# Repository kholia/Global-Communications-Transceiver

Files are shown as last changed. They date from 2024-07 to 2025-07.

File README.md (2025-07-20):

# Intro

The `Global Communications Transceiver` project. Global-Communications-Transceiver
is a 5W radio transceiver which is rugged, simple, and reliable.

It is a `optionally silent` digital radio which can be heard almost all over
the world!

Note: Receiving amateur and CB radio traffic without any license is fine in
most countries - please check your local regulations to be sure. Transmitting
on amateur shortwave bands usually requires an amateur radio license but you
are free to transmit and experiment on the CB band.

https://en.wikipedia.org/wiki/Citizens_band_radio_in_India

## Render

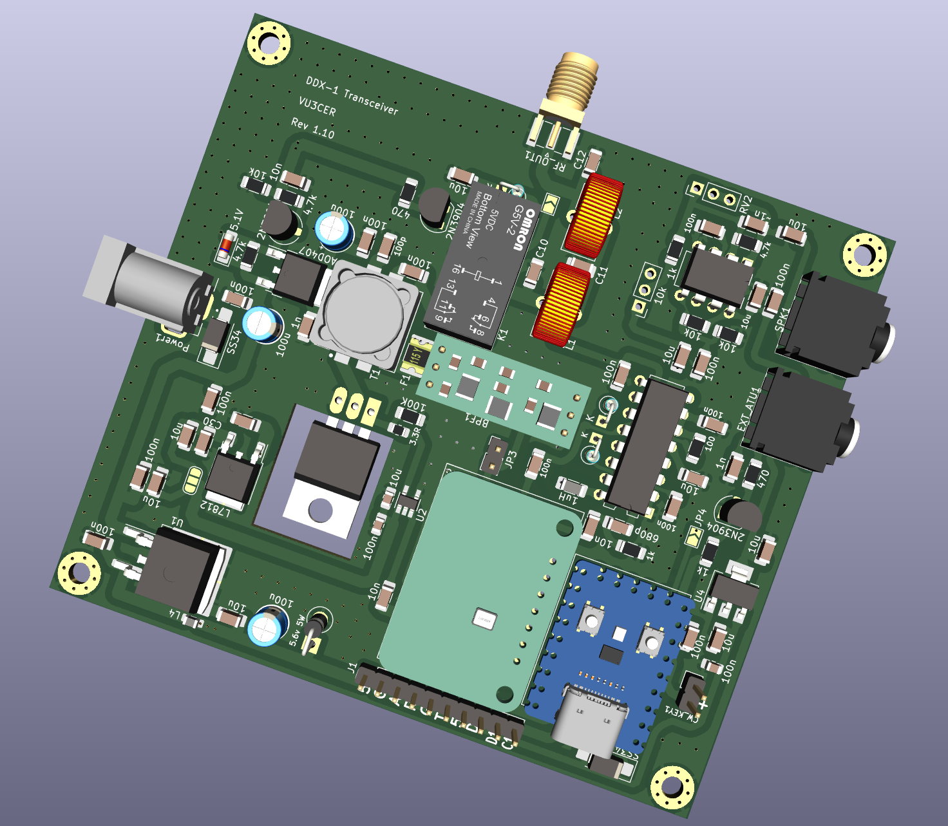
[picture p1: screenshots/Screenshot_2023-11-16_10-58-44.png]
Render


## Results

Sample contact from Pune to Medellin on 10m (15691km):

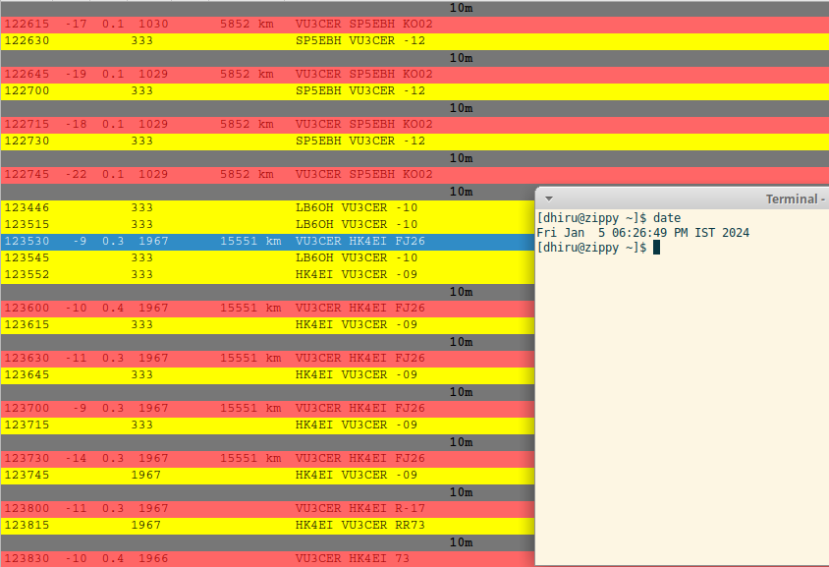
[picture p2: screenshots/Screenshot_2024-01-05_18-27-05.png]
Medellin QSO


Another sample conact with `WW1WW` (Pune to USA):

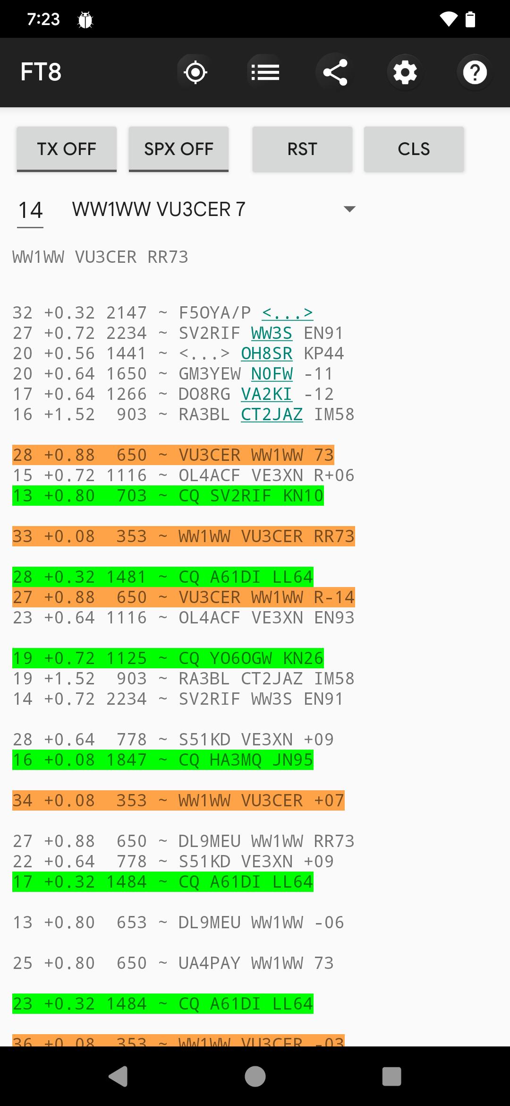
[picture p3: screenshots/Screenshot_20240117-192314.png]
USA QSO


## Features

- Single USB-C cable for handling both Audio + CAT control

- True 5W output on all HF bands. It even outputs ~1-2 W @ 50 MHz! (We now just
  need a 6m capable receiver section to build a 6m digital transceiver).

- Rock-solid PA which handles open, short, and bad SWR conditions (1:10 SWR
  tested). We knowingly stress-test it with untuned antennas and still manage
  DX (not a recommended practice for sure though).

- Rock-steady VFO which does NOT drift even under exposed conditions.  Yes - it
  receives WSPR at 28 MHz just fine.

- Reliable T/R switching based on a DPDT relay

- Switchable BPF support to get rid of BCI and other interferences (tested
  against OTH radar + 100 kW AM station in close visual proximity)

- No toroids to wind assuming an external LPF bank is in use ;-)

- The IRF510 final remains as cool as a cucumber (Class-D operation).

- Avoids problems associated with the 'audio frequency counting' approach used
  by earlier designs. Our transceiver has a bit-perfect, deterministic TX output.

- Supports largely automated assembly from JLCPCB (all the required files are
  in the same GitHub repository)

- It comes with a free, open-source AGPLv3 licensed firmware.

- No calibration is (ever) required. Just pick it up and it is ready to go
  on air.

- Low cost (20 to 30 USD is our BOM estimate)

- Stress tested by WSJT-Z for multiple days

- It routinely receives FT8 traffic from 80 to 100+ countries using a simple 5m
  long EFHW antenna

## RX Performance

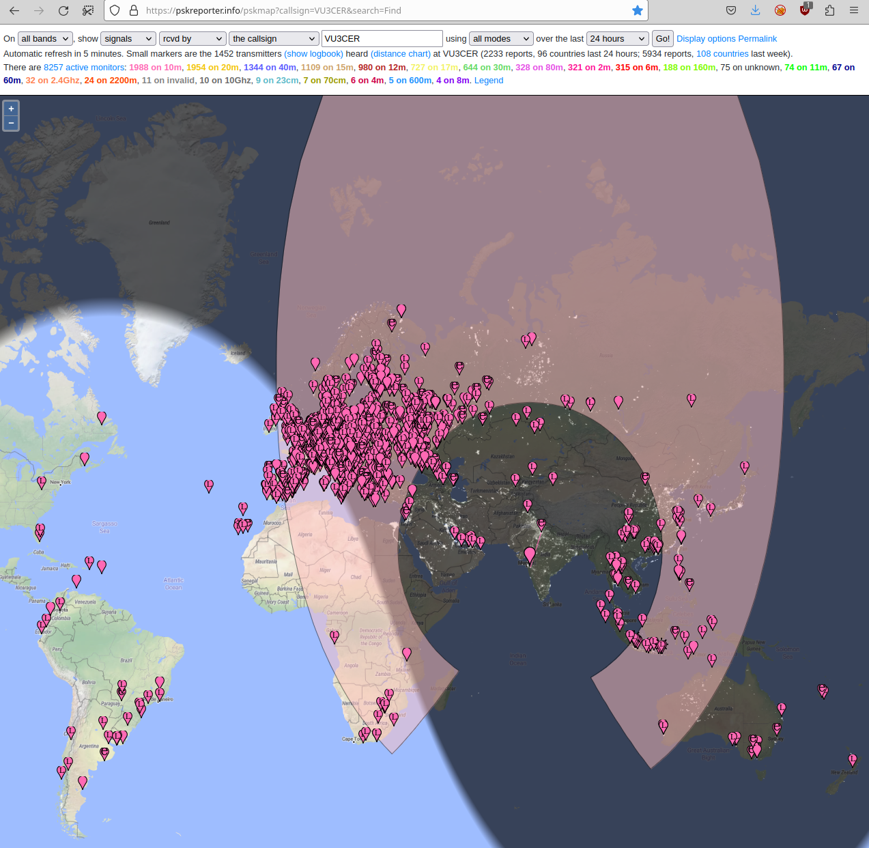
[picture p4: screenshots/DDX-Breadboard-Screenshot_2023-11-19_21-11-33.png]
RX Performance


Performance of CD2003-with-BPF is >= 80% of that of RSP1 SDR, at least!

## TX Performance

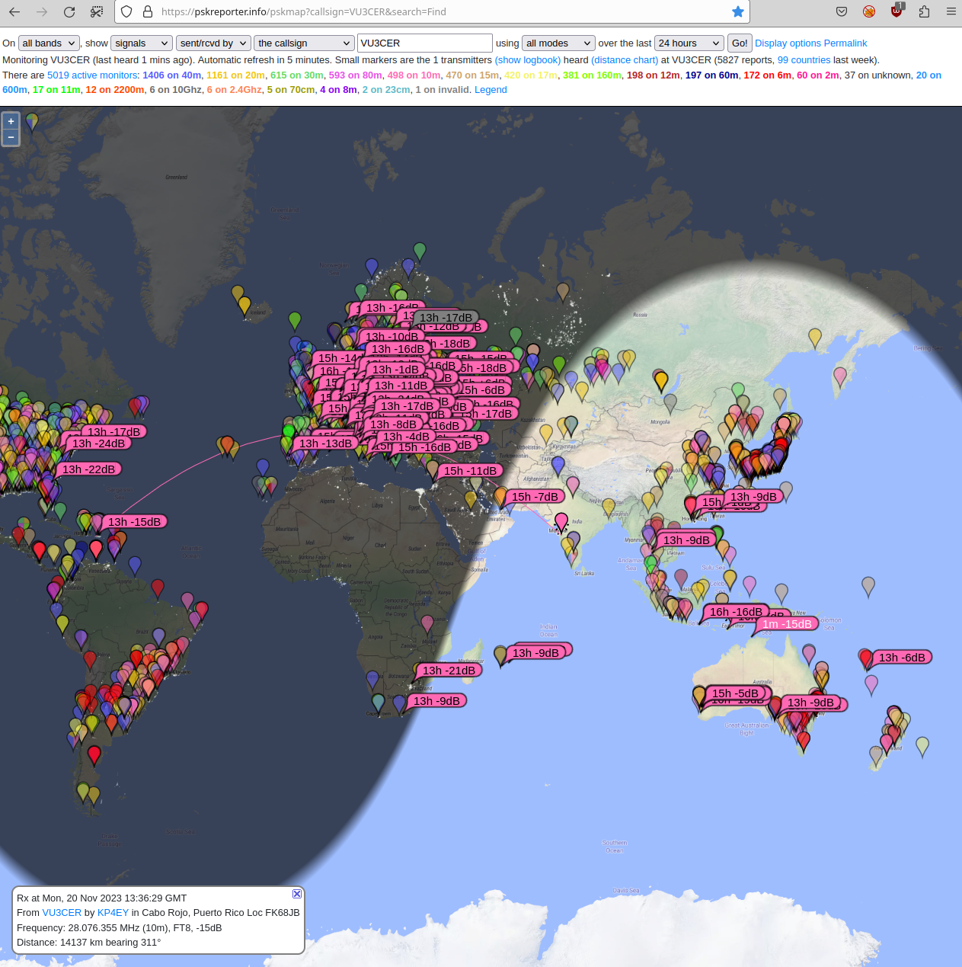
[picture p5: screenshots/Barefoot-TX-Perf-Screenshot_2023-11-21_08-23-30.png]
TX Performance


## VFO stability

It receives WSPR @ 28 MHz ;)

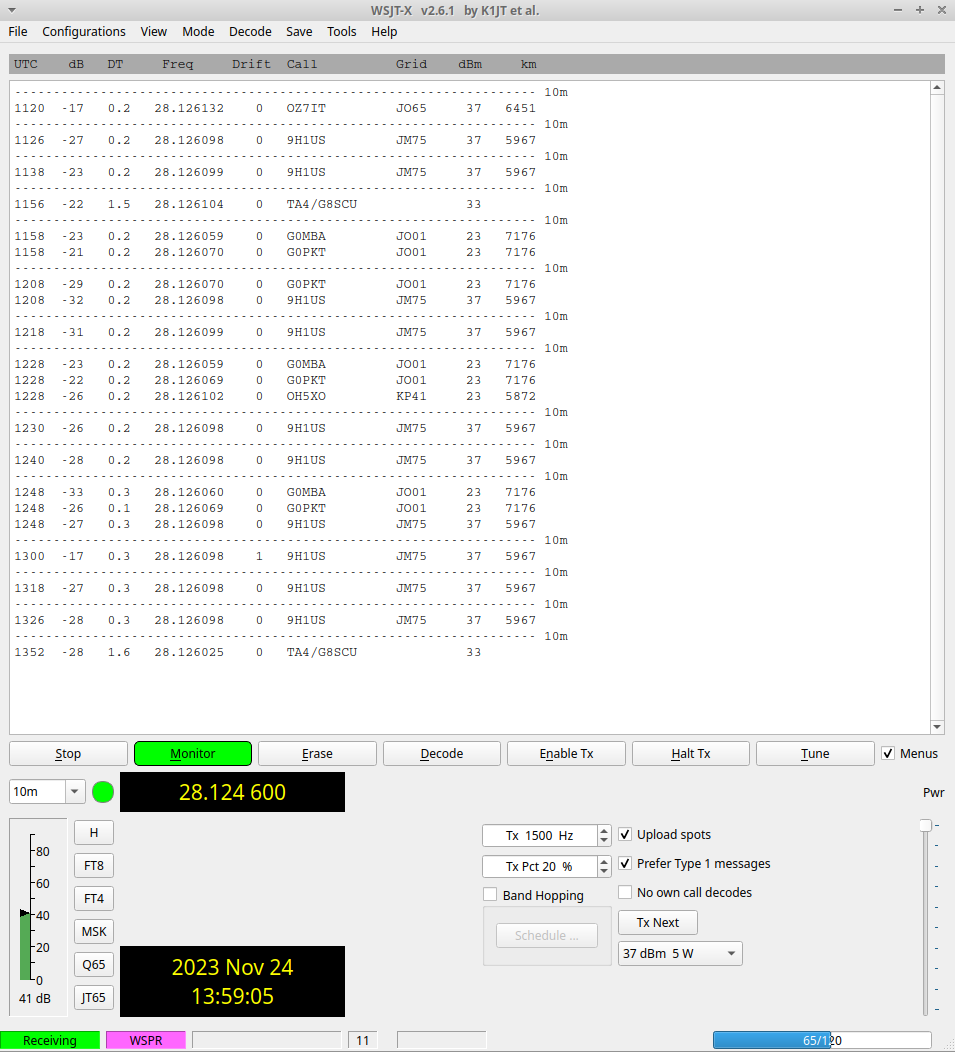
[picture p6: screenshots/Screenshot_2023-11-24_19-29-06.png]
WSPR stability


## WSPR TX Performance

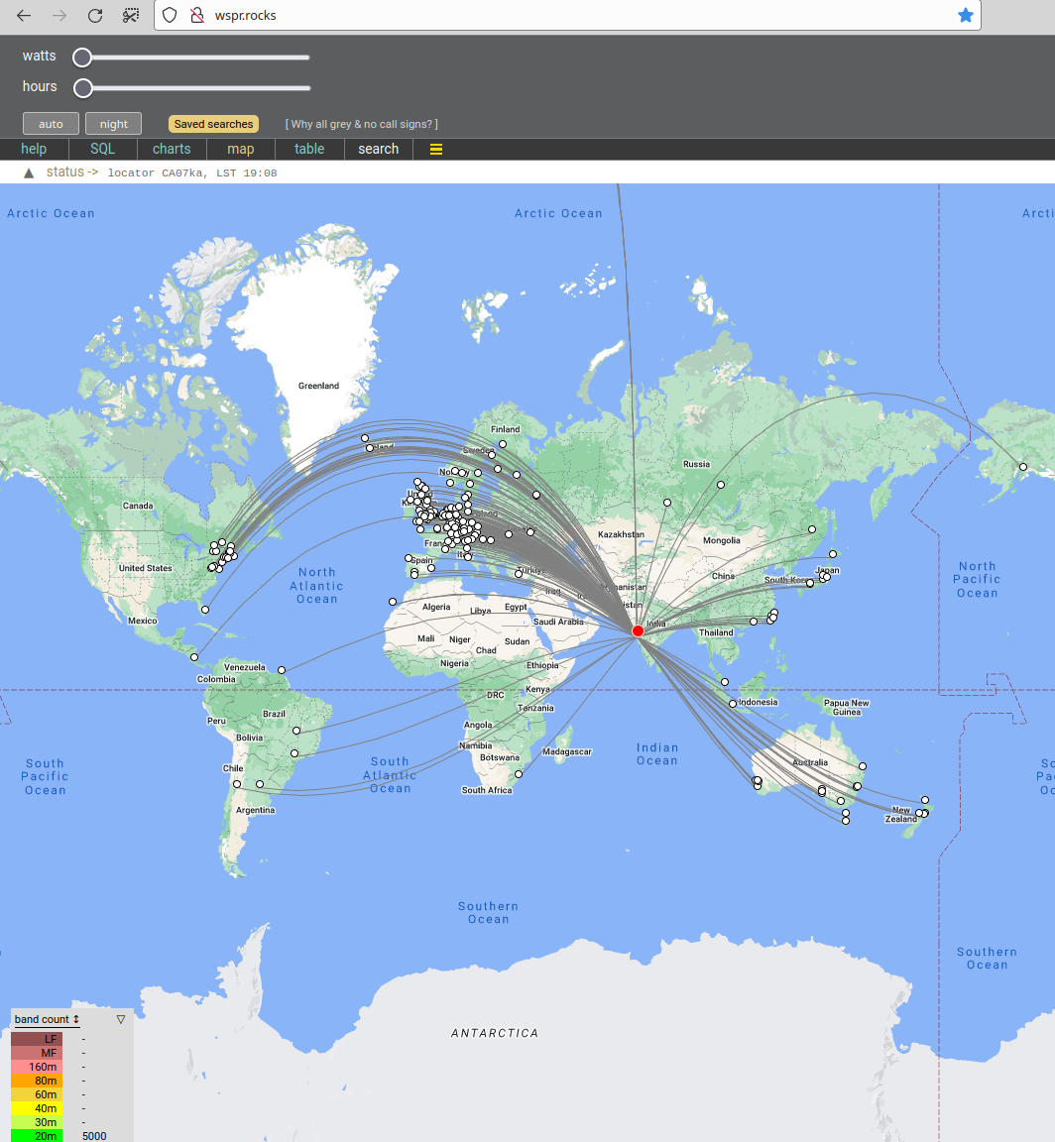
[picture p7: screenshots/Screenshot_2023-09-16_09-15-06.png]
WSPR TX performance


## Files

With these files, you can get around 80% pre-assembled boards (with the SMD
components soldered) from JLCPCB at a minimal cost.

- [BOM](./design-files/HF-PA-v10.csv)

- [Gerbers + PCBA files](./design-files/jlcpcb/production_files)

- [Schematic](./design-files/Schematics.pdf)

Note: The Si5351+TCXO boards can be ordered in fully assembled form from
JLCPCB. https://github.com/kholia/Si5351-Module-Clone-TCXO/ has the required
files (use the `-v4` folder).

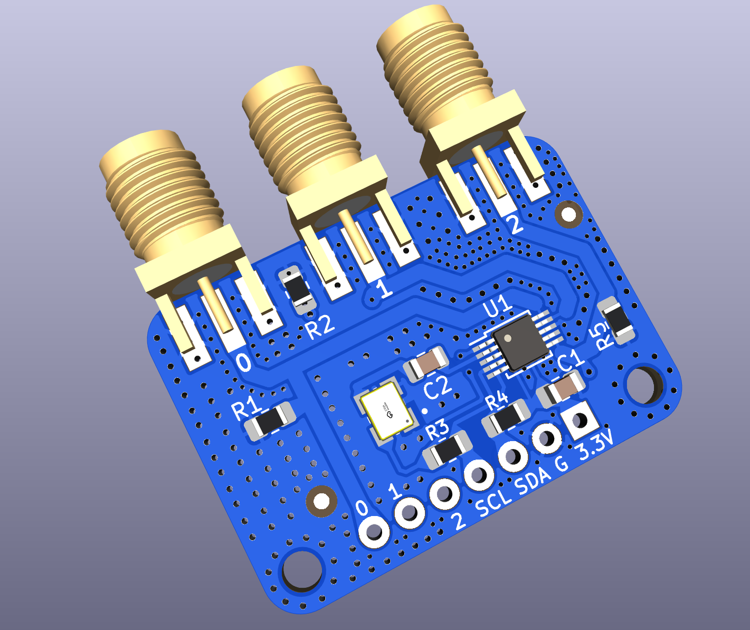
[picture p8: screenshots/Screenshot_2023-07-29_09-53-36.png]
Si5351 TCXO boards


JLCPCB link: https://jlcpcb.com/

JLCPCB ordering guide: https://github.com/WB2CBA/ADX-UnO-V1.3/ has the JLCPCB
ordering guide in it.

## Building the firmware (for Linux users)

Shortcut: Upload the pre-built `.uf2` file to the RP2040 Board and skip
to the next section.

Install dependencies:

```
sudo apt install cmake gcc-arm-none-eabi libnewlib-arm-none-eabi \
  libstdc++-arm-none-eabi-newlib git libusb-1.0-0-dev build-essential \
  make g++ gcc
```

```
mkdir ~/repos
cd ~/repos
```

```
git clone --recursive https://github.com/kholia/tinyusb.git  # use this in pico-sdk
git clone --recursive https://github.com/raspberrypi/pico-sdk.git
git clone --recursive https://github.com/kholia/Global-Communications-Transceiver.git
```

Now build the firmware using instructions in the `firmware` folder.

Load the built `.uf2` file into the MCU board. Process: Hold the BOOT button on
RP2040-Zero, and then connect it to a computer. Release the BOOT button. A new
drive will open on the computer. Just drag the .uf2 firmware file (included in
the repository) to this new drive. Done!

## Power sources

The transceiver was tested with the following power sources.

- SUGON 3005D Adjustable Digital DC Power - RECOMMENDED

- 3S "12V" Li-ion 18650 battery pack (RECOMMENDED for field operations)

- RUIDENG DPS5020 power supply module (@13v) powered by MEAN WELL / Mornsun SMPS

## Tips and Hints

- Do NOT use the internal LPF + BPF filters. Just use https://github.com/kholia/DDX/tree/master/RX-TX-BPF-2025-v2 externally.

- IRF510 needs to be insulated from the heat sink.

- You can ignore the `External ATU jack` stuff.

- Use a Common-Mode-Choke (attached between the rig, and the antenna) for
  safety against `return/back RF`.

- DDX works seamlessly with https://play.google.com/store/apps/details?id=com.bunzee.ft8radio app!

## Resources

- The `Global Communications Transceiver` project comes from our DDX family of
  transceiver designs - https://github.com/kholia/DDX/

- https://rf-tools.com/lc-filter/

- https://github.com/WB2CBA/ADX (the design that started it all)

- http://www.learningaboutelectronics.com/Articles/Low-pass-filter-calculator.php

- https://github.com/kholia/ConsensusBasedTimeSync (receiver comes from here)

- https://github.com/kholia/Si5351-Module-Clone-TCXO/ (VFO comes from here)

- https://github.com/kholia/HF-PA-v10 (PA comes from here)

  Ruggedness philosophy: https://www.youtube.com/watch?v=4r7wHMg5Yjg

- https://www.kk5jy.net/three-wire-gp/ (recommended antenna - superb for DX)

- https://github.com/kholia/HF-Balcony-Antenna-System (another portable antenna setup)

- https://github.com/batica81/microphone-library-for-pico (Vojislav's work makes DDX-1 possible)

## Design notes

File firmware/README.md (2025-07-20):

Build Process:

NB: https://github.com/hathach/tinyusb/pull/3181

```
export PICO_SDK_PATH=$HOME/repos/pico-sdk

export PICO_BOARD=waveshare_rp2040_zero  # note

cmake .

cmake -DCMAKE_BUILD_TYPE=Release .

make -j8
```

```
$ pacmd list-sources
...
  * index: 4
	name: <alsa_input.usb-PaniRCorp_MicNode_123456-00.mono-fallback>
	driver: <module-alsa-card.c>
	flags: HARDWARE HW_MUTE_CTRL HW_VOLUME_CTRL DECIBEL_VOLUME LATENCY DYNAMIC_LATENCY
	state: RUNNING
	suspend cause: (none)
	priority: 9040
	volume: mono: 65536 / 100% / 0.00 dB
	        balance 0.00
	base volume: 64662 /  99% / -0.35 dB
	volume steps: 65537
	muted: no
	current latency: 2.54 ms
	max rewind: 0 KiB
	sample spec: s16le 1ch 16000Hz
	channel map: mono
	             Mono
	used by: 1
	linked by: 1
	configured latency: 24.99 ms; range is 0.50 .. 2000.00 ms
	card: 7 <alsa_card.usb-PaniRCorp_MicNode_123456-00>
	module: 31
	properties:
		alsa.resolution_bits = "16"
		device.api = "alsa"
		device.class = "sound"
		alsa.class = "generic"
		alsa.subclass = "generic-mix"
		alsa.name = "USB Audio"
		alsa.id = "USB Audio"
		alsa.subdevice = "0"
		alsa.subdevice_name = "subdevice #0"
		alsa.device = "0"
		alsa.card = "4"
		alsa.card_name = "MicNode"
		alsa.long_card_name = "PaniRCorp MicNode at usb-0000:04:00.4-1.3.2, full speed"
		alsa.driver_name = "snd_usb_audio"
		device.bus_path = "pci-0000:04:00.4-usb-0:1.3.2:1.0"
		sysfs.path = "/devices/pci0000:00/0000:00:08.1/0000:04:00.4/usb3/3-1/3-1.3/3-1.3.2/3-1.3.2:1.0/sound/card4"
		udev.id = "usb-PaniRCorp_MicNode_123456-00"
		device.bus = "usb"
		device.vendor.id = "cafe"
		device.vendor.name = "PaniRCorp"
		device.product.id = "4011"
		device.product.name = "MicNode"
		device.serial = "PaniRCorp_MicNode_123456"
		device.string = "hw:4"
		device.buffering.buffer_size = "64000"
		device.buffering.fragment_size = "32000"
		device.access_mode = "mmap+timer"
		device.profile.name = "mono-fallback"
		device.profile.description = "Mono"
		device.description = "MicNode Mono"
		module-udev-detect.discovered = "1"
		device.icon_name = "audio-card-usb"
	ports:
		analog-input-mic: Microphone (priority 8700, latency offset 0 usec, available: yes)
			properties:
				device.icon_name = "audio-input-microphone"
	active port: <analog-input-mic>
```

The latency and peformance of the emulated microphone is fine. Check by
recording from this device using Audacity.

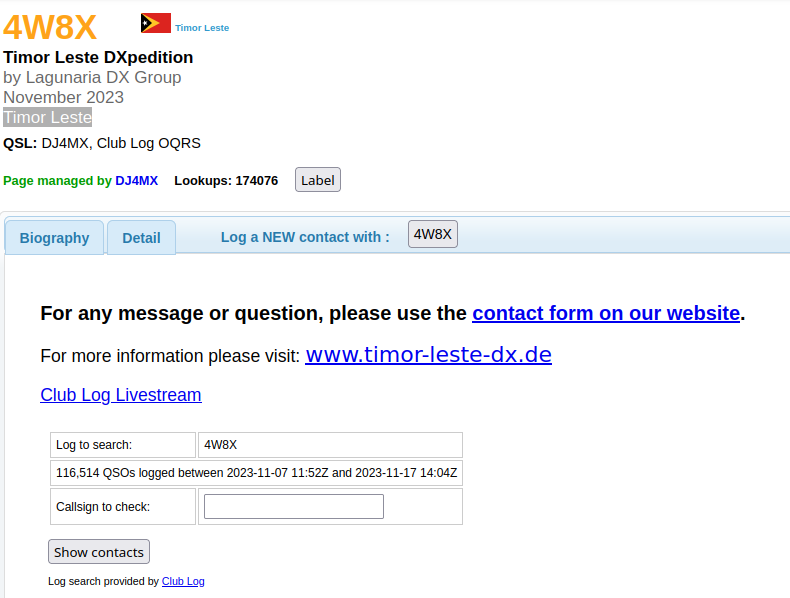
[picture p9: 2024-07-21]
screenshots/Screenshot_2023-11-17_19-35-13.png

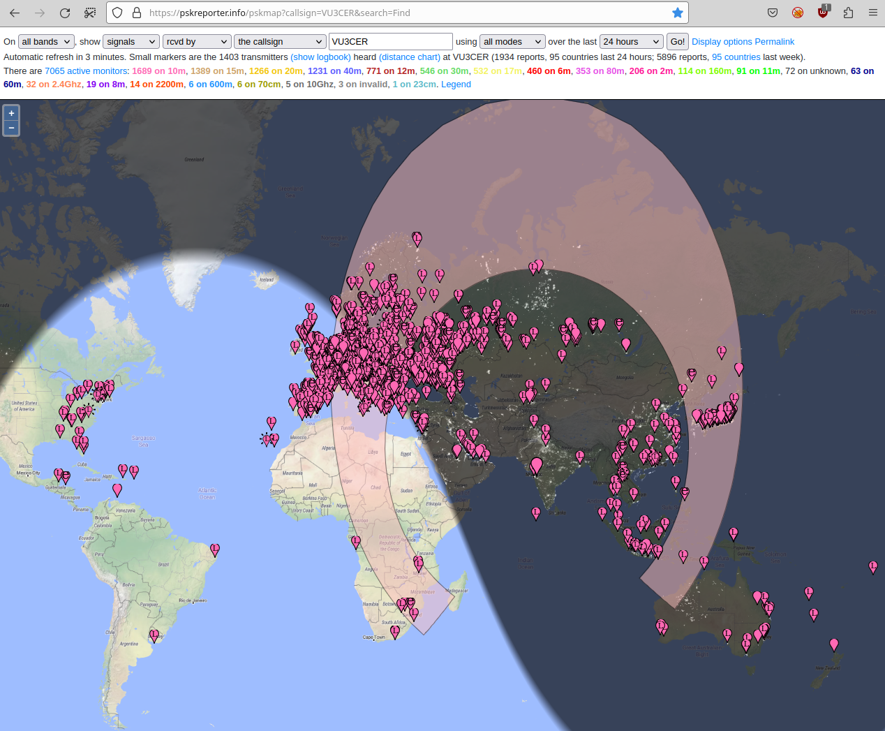
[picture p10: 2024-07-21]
screenshots/RX-Screenshot_2023-11-30_20-05-11.png

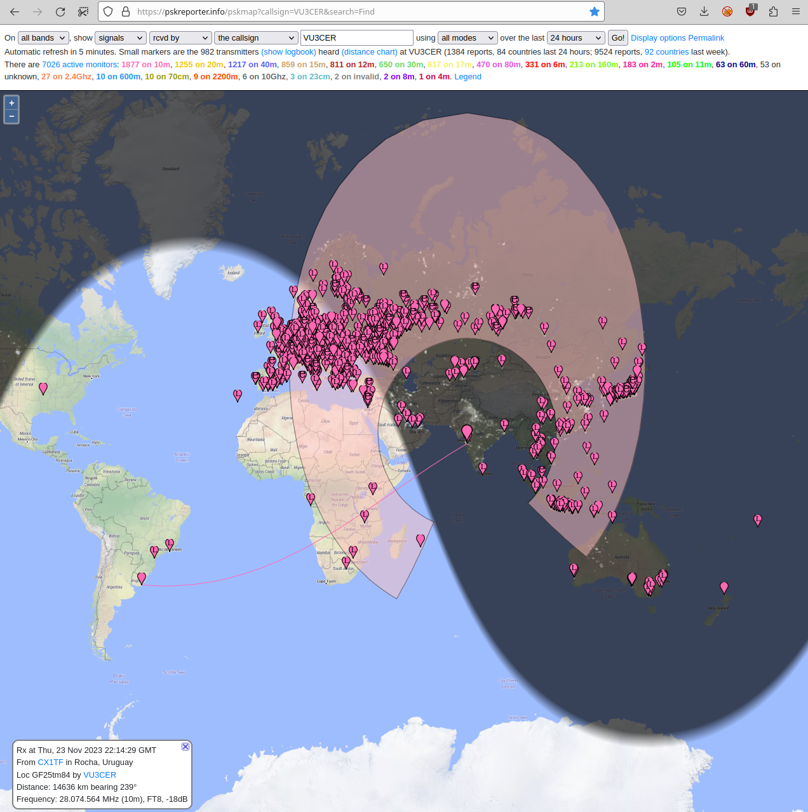
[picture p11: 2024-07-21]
screenshots/Screenshot_2023-11-24_19-33-11.png

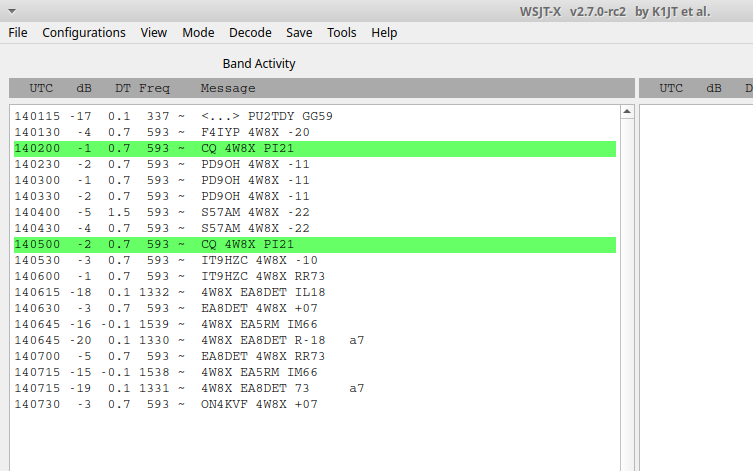
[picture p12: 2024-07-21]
screenshots/Screenshot_2023-11-17_19-37-47.png

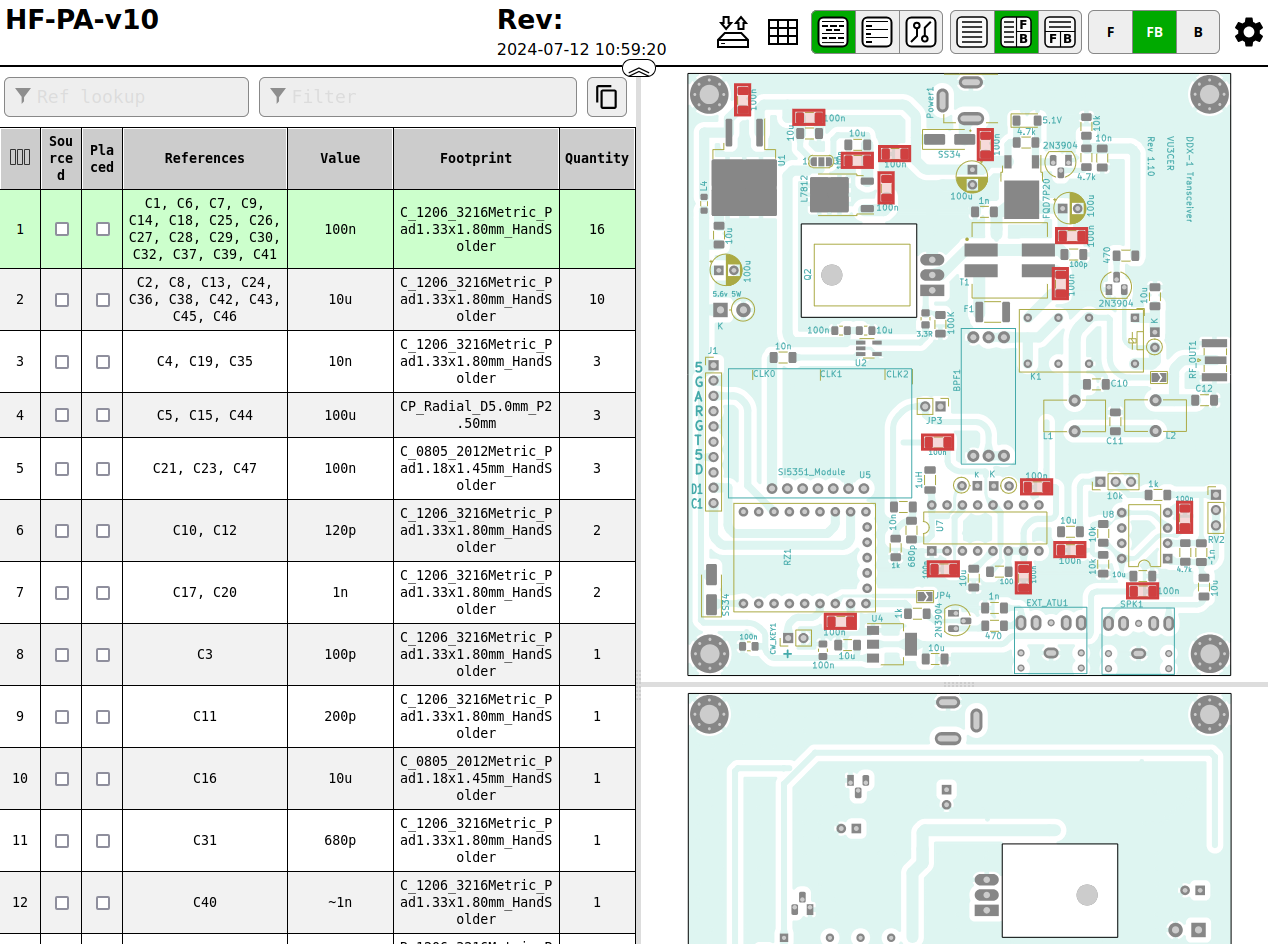
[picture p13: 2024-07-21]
screenshots/Screenshot_2024-07-12_13-24-04.png

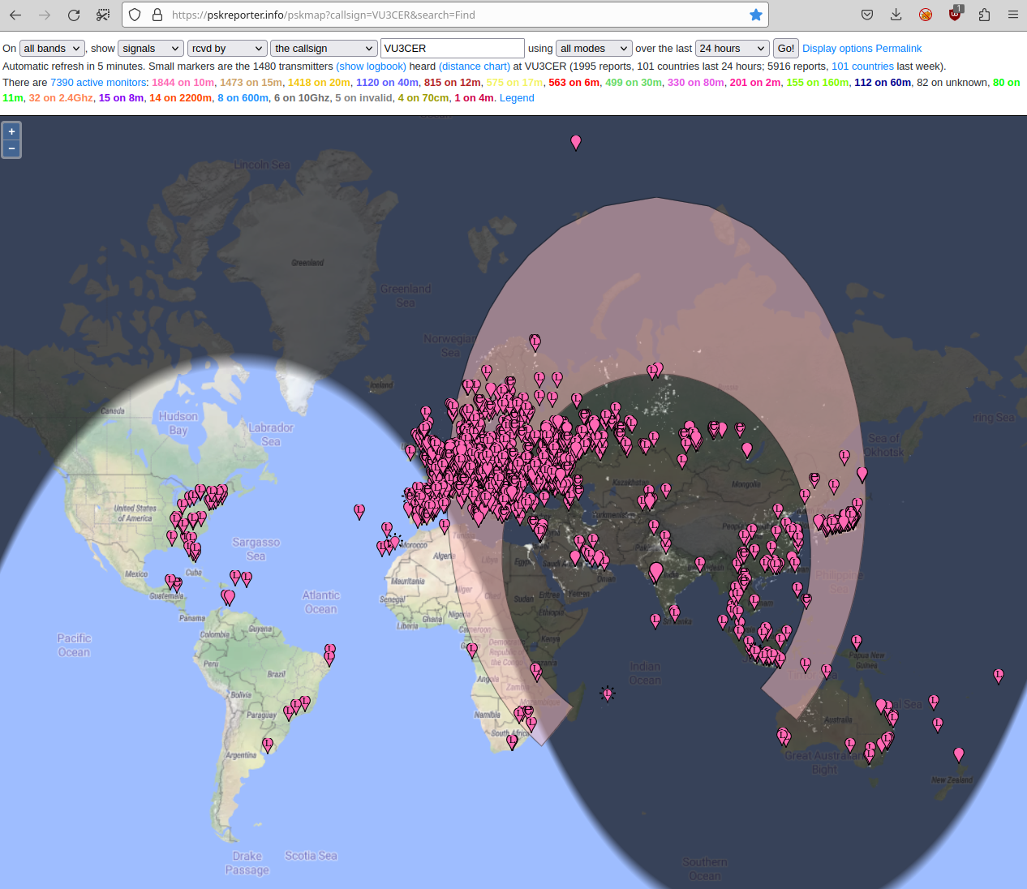
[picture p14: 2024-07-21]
screenshots/RX-Screenshot_2023-11-30_21-44-51.png

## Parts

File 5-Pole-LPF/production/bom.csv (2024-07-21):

Designator | Footprint | Quantity | Value | LCSC Part #
C1, C2, C3, C4, C5, C6 | C_Disc_D5.0mm_W2.5mm_P5.00mm | 6 | 100n
H1, H2, H3, H4 | MountingHole_2.2mm_M2_Pad_Via | 4 | MountingHole_Pad
IN1, OUT1 | SMA_Samtec_SMA-J-P-H-ST-EM1_EdgeMount | 2 | SMA
L1, L2 | L_Toroid_Vertical_L10.0mm_W5.0mm_P5.08mm | 2 | L_Small

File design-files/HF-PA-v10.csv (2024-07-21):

Reference | Value | Footprint | Datasheet | Source | Voltage | Qty
BPF1 | Pluggable BPF | footprints:Pluggable-BPF |  | JLCPCB(A) |  | 1
C1, C6, C7, C9, C14, C18, C25-C30, C32, C37, C39, C41 | 100n | Capacitor_SMD:C_1206_3216Metric_Pad1.33x1.80mm_HandSolder | ~ | LCSC | -- mixed values -- | 16
C2, C8, C13, C24, C38, C42, C43, C45, C46 | 10u | Capacitor_SMD:C_1206_3216Metric_Pad1.33x1.80mm_HandSolder | ~ | LCSC |  | 9
C3 | 100p | Capacitor_SMD:C_1206_3216Metric_Pad1.33x1.80mm_HandSolder | ~ | LCSC |  | 1
C4, C19, C35 | 10n | Capacitor_SMD:C_1206_3216Metric_Pad1.33x1.80mm_HandSolder | ~ | LCSC |  | 3
C5, C15, C44 | 100u | Capacitor_THT:CP_Radial_D5.0mm_P2.50mm | ~ | LCSC |  | 3
C10, C12 | 120p | Capacitor_SMD:C_1206_3216Metric_Pad1.33x1.80mm_HandSolder | ~ | LCSC |  | 2
C11 | 200p | Capacitor_SMD:C_1206_3216Metric_Pad1.33x1.80mm_HandSolder | ~ | LCSC |  | 1
C16 | 10u | Capacitor_SMD:C_0805_2012Metric_Pad1.18x1.45mm_HandSolder | ~ | LCSC |  | 1
C17, C20 | 1n | Capacitor_SMD:C_1206_3216Metric_Pad1.33x1.80mm_HandSolder | ~ | LCSC |  | 2
C21, C23, C47 | 100n | Capacitor_SMD:C_0805_2012Metric_Pad1.18x1.45mm_HandSolder | ~ | LCSC |  | 3
C31 | 680p | Capacitor_SMD:C_1206_3216Metric_Pad1.33x1.80mm_HandSolder | ~ | LCSC |  | 1
C36 | 10u | Capacitor_SMD:C_1206_3216Metric_Pad1.33x1.80mm_HandSolder | ~ | LCSC |  | 1
C40 | ~1n | Capacitor_SMD:C_1206_3216Metric_Pad1.33x1.80mm_HandSolder | ~ | LCSC |  | 1
CW_KEY1 | Conn_01x02 | Connector_PinHeader_2.54mm:PinHeader_1x02_P2.54mm_Vertical | ~ | NA |  | 1
D1, D2 | SS34 | Diode_SMD:D_SMA_Handsoldering | https://www.tme.eu/Document/4534c3d1273464918563ce78bdeb2ece/SS34-E3-57T.pdf | LCSC |  | 2
D3, D8, D9 | 1N4148 | Diode_THT:D_DO-35_SOD27_P2.54mm_Vertical_KathodeUp | https://www.vishay.com/docs/81857/1n4148.pdf | LCSC |  | 3
D4 | 5.1V | Diode_SMD:D_MiniMELF | ~ | LCSC |  | 1
D5 | 5.6v 5W | Diode_THT:D_DO-15_P3.81mm_Vertical_KathodeUp | ~ | LCSC |  | 1
EXT_ATU1 | EXT_ATU | footprints:PJ-307_Modded | https://cdn.hackaday.io/files/1813827760247488/JW-PJ-307-5_35mm-stereo-pcb-socket.pdf |  |  | 1
F1 | 2A | Fuse:Fuse_1812_4532Metric_Pad1.30x3.40mm_HandSolder | ~ | LCSC |  | 1
H1-H4 | MountingHole_Pad | MountingHole:MountingHole_3.2mm_M3_Pad_Via | ~ | NA |  | 4
J1 | Conn_01x06 | Connector_PinHeader_2.54mm:PinHeader_1x10_P2.54mm_Vertical | ~ | NA |  | 1
JP1, JP4 | Jumper_2_Open | Jumper:SolderJumper-2_P1.3mm_Open_TrianglePad1.0x1.5mm | ~ | NA |  | 2
JP2 | Power_Switch | Jumper:SolderJumper-3_P1.3mm_Open_RoundedPad1.0x1.5mm_NumberLabels | ~ | NA |  | 1
JP3 | Jumper_2_Open | Connector_PinHeader_2.54mm:PinHeader_1x02_P2.54mm_Vertical | ~ | NA |  | 1
K1 | Omron G5V-2 / OEN 46-05-2C | Relay_THT:Relay_DPDT_Omron_G5V-2 | http://omronfs.omron.com/en_US/ecb/products/pdf/en-g5v_2.pdf | LCSC |  | 1
L1, L2 | 360n | Inductor_THT:L_Toroid_Vertical_L10.0mm_W5.0mm_P5.08mm | ~ | DIY on Toroid |  | 2
L4 | Ferrite Bead (2A) | Inductor_SMD:L_0805_2012Metric_Pad1.05x1.20mm_HandSolder | 330Ohm 2.5A 25% 0805 Multilayer Chip Ferrite Bead - UPZ2012E331-2R5TF - Shenzhen Sunlord - LCSC | LCSC |  | 1
L5 | 1uH | Inductor_SMD:L_1206_3216Metric_Pad1.22x1.90mm_HandSolder | ~ | LCSC |  | 1
Power1 | DC-005 (Barrel Jack) | footprints:XKB_DC-005-5A-2.0_Modded | https://www.lcsc.com/product-detail/Power-Connectors_XKB-Enterprise-DC-005-5A-2-0_C381116.html | LCSC |  | 1
Q1, Q4, Q5 | 2N3904 | Package_TO_SOT_THT:TO-92_HandSolder | https://www.onsemi.com/pdf/datasheet/2n3903-d.pdf | LCSC |  | 3
Q2 | IRF510 | Package_TO_SOT_THT:TO-220-3_Horizontal_TabDown | https://www.lcsc.com/product-detail/MOSFETs_Vishay-Intertech-IRFI510GPBF_C506484.html | Mouser / LCSC (IRFI510G) |  | 1
Q3 | AOD407 | Package_TO_SOT_SMD:TO-252-2 | http://aosmd.com/pdfs/datasheet/AOD407.pdf | LCSC |  | 1
R1 | 100K | Resistor_SMD:R_1206_3216Metric_Pad1.30x1.75mm_HandSolder | ~ | LCSC |  | 1
R2, R10, R11 | 10k | Resistor_SMD:R_1206_3216Metric_Pad1.30x1.75mm_HandSolder | ~ | LCSC |  | 3
R4 | 470 | Resistor_SMD:R_1206_3216Metric_Pad1.30x1.75mm_HandSolder | ~ | LCSC |  | 1
R6 | 100 | Resistor_SMD:R_1206_3216Metric_Pad1.30x1.75mm_HandSolder | ~ | LCSC |  | 1
R7 | 1k | Resistor_SMD:R_1206_3216Metric_Pad1.30x1.75mm_HandSolder | ~ | LCSC |  | 1
R8, R9 | 4.7k | Resistor_SMD:R_1206_3216Metric_Pad1.30x1.75mm_HandSolder | ~ | LCSC |  | 2
R12 | 3.3R | Resistor_SMD:R_0805_2012Metric_Pad1.20x1.40mm_HandSolder | ~ | LCSC or short (preferred)! |  | 1
Rb1 | 1k | Resistor_SMD:R_1206_3216Metric_Pad1.30x1.75mm_HandSolder | ~ | LCSC |  | 1
Rf1 | 4.7k | Resistor_SMD:R_1206_3216Metric_Pad1.30x1.75mm_HandSolder | ~ | LCSC |  | 1
RF_OUT1 | SMA | Connector_Coaxial:SMA_Samtec_SMA-J-P-X-ST-EM1_EdgeMount | ~ | LCSC / https://www.ktron.in/ |  | 1
Rin1 | 1k | Resistor_SMD:R_1206_3216Metric_Pad1.30x1.75mm_HandSolder | ~ | LCSC |  | 1
Rl1 | 470 | Resistor_SMD:R_1206_3216Metric_Pad1.30x1.75mm_HandSolder | ~ | LCSC |  | 1
RV1 | 10k | Connector_PinHeader_2.54mm:PinHeader_1x03_P2.54mm_Vertical | ~ | NA |  | 1
RV2 | 20k | Connector_PinHeader_2.54mm:PinHeader_1x03_P2.54mm_Vertical | ~ | NA |  | 1
RZ1 | RP2040-Zero | footprints:RP2040-Zero | https://www.waveshare.com/wiki/RP2040-Zero |  |  | 1
SPK1 | SPEAKER | footprints:PJ-307_Modded | https://cdn.hackaday.io/files/1813827760247488/JW-PJ-307-5_35mm-stereo-pcb-socket.pdf |  |  | 1
T1 | Bifilar XFMR | footprints:IND_SRF1260A-4R7Y-Longer-Pads | https://www.digikey.com/en/products/detail/bourns-inc/SRF1260A-4R7Y/4340156 | Mouser / DigiKey / Farnell |  | 1
U1 | L7805 (D2PAK) | Package_TO_SOT_SMD:TO-263-2 | https://www.st.com/resource/en/datasheet/l78.pdf | LCSC |  | 1
U2 | UCC27517ADBVR | Package_TO_SOT_SMD:SOT-23-5_HandSoldering | https://www.lcsc.com/product-detail/Gate-Drive-ICs_Texas-Instruments-UCC27517ADBVR_C2653784.html | LCSC |  | 1
U3 | L7812 | Package_TO_SOT_SMD:TO-252-2 | https://www.st.com/resource/en/datasheet/l78.pdf | LCSC |  | 1
U4 | AMS1117-3.3 | Package_TO_SOT_SMD:SOT-223-3_TabPin2 | http://www.advanced-monolithic.com/pdf/ds1117.pdf | LCSC (Hottech make is fine!) |  | 1
U5 | SI5351_Module | footprints:SI5351 Module | https://github.com/kholia/Si5351-Module-Clone-TCXO/ (MUST!) | TCXO is a must! |  | 1
U7 | CD2003GB_GP | Package_DIP:DIP-16_W7.62mm | https://www.ak-modul-bus.de/cat/documentation/CD2003.pdf | eBay / https://inkocean.in/ |  | 1
U8 | MCP6002 | Package_DIP:DIP-8_W7.62mm | https://www.microchip.com/en-us/product/mcp6002 | Mouser / DigiKey / Semikart |  | 1

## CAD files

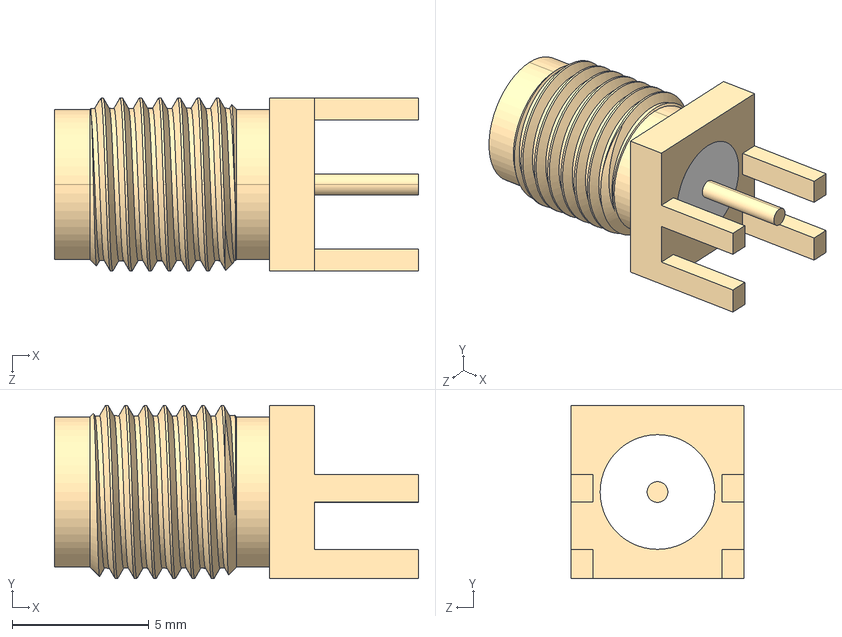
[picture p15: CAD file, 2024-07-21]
5-Pole-LPF/models/CON-SMA-EDGE-S--3DModel-STEP-56544.STEP
13.3 x 6.35 x 6.35 mm

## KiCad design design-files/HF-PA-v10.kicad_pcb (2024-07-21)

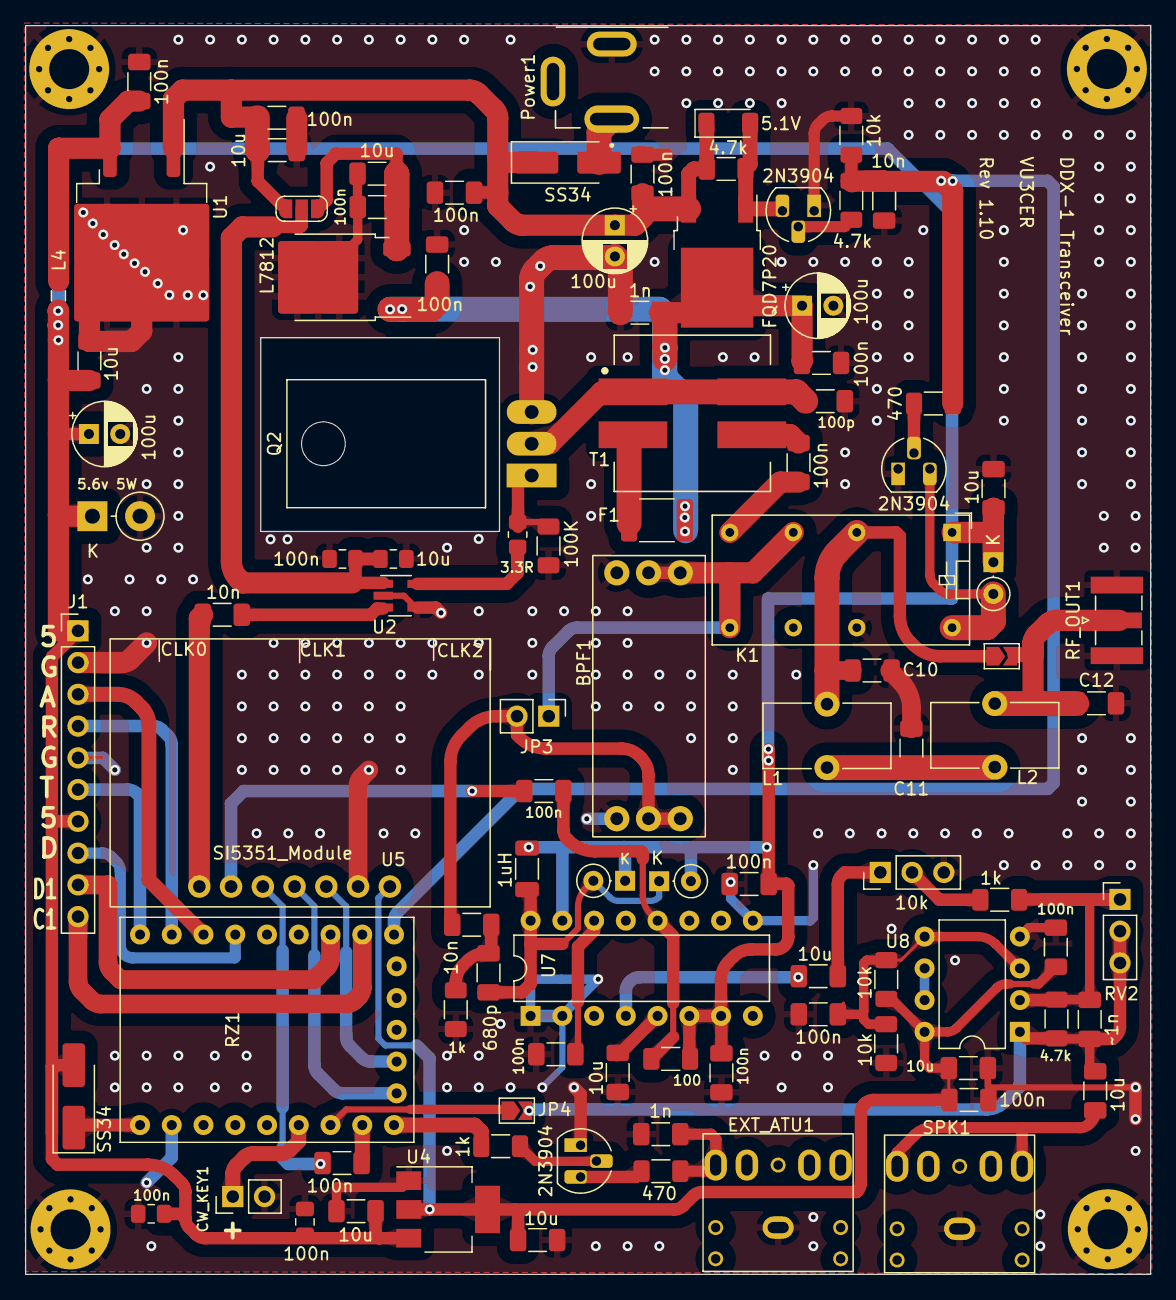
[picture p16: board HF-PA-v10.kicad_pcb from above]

Board: 2 copper layers, 90.0 x 99.9 mm, 102 parts (0 on the bottom side), 58 nets.

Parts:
BPF1: Pluggable BPF; Pluggable-BPF
C1, C6, C7, C9, C14, C18, C25, C26, C27, C28, C29, C30, C32, C37, C39, C41: 100n; C_1206_3216Metric_Pad1.33x1.80mm_HandSolder
C2, C8, C13, C24, C36, C38, C42, C43, C45, C46: 10u; C_1206_3216Metric_Pad1.33x1.80mm_HandSolder
C3: 100p; C_1206_3216Metric_Pad1.33x1.80mm_HandSolder
C4, C19, C35: 10n; C_1206_3216Metric_Pad1.33x1.80mm_HandSolder
C5, C15, C44: 100u; CP_Radial_D5.0mm_P2.50mm
C10, C12: 120p; C_1206_3216Metric_Pad1.33x1.80mm_HandSolder
C11: 200p; C_1206_3216Metric_Pad1.33x1.80mm_HandSolder
C16: 10u; C_0805_2012Metric_Pad1.18x1.45mm_HandSolder
C17, C20: 1n; C_1206_3216Metric_Pad1.33x1.80mm_HandSolder
C21, C23, C47: 100n; C_0805_2012Metric_Pad1.18x1.45mm_HandSolder
C31: 680p; C_1206_3216Metric_Pad1.33x1.80mm_HandSolder
C40: ~1n; C_1206_3216Metric_Pad1.33x1.80mm_HandSolder
CW_KEY1: Conn_01x02; PinHeader_1x02_P2.54mm_Vertical
D1, D2: SS34; D_SMA_Handsoldering
D3, D8, D9: 1N4148; D_DO-35_SOD27_P2.54mm_Vertical_KathodeUp
D4: 5.1V; D_MiniMELF
D5: 5.6v 5W; D_DO-15_P3.81mm_Vertical_KathodeUp
EXT_ATU1: EXT_ATU; PJ-307_Modded
F1: 2A; Fuse_1812_4532Metric_Pad1.30x3.40mm_HandSolder
H1, H2, H3, H4: MountingHole_Pad; MountingHole_3.2mm_M3_Pad_Via
J1: Conn_01x06; PinHeader_1x10_P2.54mm_Vertical
JP1, JP4: Jumper_2_Open; SolderJumper-2_P1.3mm_Open_TrianglePad1.0x1.5mm
JP2: Power_Switch; SolderJumper-3_P1.3mm_Open_RoundedPad1.0x1.5mm_NumberLabels
JP3: Jumper_2_Open; PinHeader_1x02_P2.54mm_Vertical
K1: Omron G5V-2 / OEN 46-05-2C; Relay_DPDT_Omron_G5V-2
L1, L2: 360n; L_Toroid_Vertical_L10.0mm_W5.0mm_P5.08mm
L4: Ferrite Bead (2A); L_0805_2012Metric_Pad1.05x1.20mm_HandSolder
L5: 1uH; L_1206_3216Metric_Pad1.22x1.90mm_HandSolder
Power1: DC-005 (Barrel Jack); XKB_DC-005-5A-2.0_Modded
Q1, Q4, Q5: 2N3904; TO-92_HandSolder
Q2: IRF510; TO-220-3_Horizontal_TabDown
Q3: FQD7P20; TO-252-2
R1: 100K; R_1206_3216Metric_Pad1.30x1.75mm_HandSolder
R2, R10, R11: 10k; R_1206_3216Metric_Pad1.30x1.75mm_HandSolder
R4: 470; R_1206_3216Metric_Pad1.30x1.75mm_HandSolder
R6: 100; R_1206_3216Metric_Pad1.30x1.75mm_HandSolder
R7: 1k; R_1206_3216Metric_Pad1.30x1.75mm_HandSolder
R8, R9: 4.7k; R_1206_3216Metric_Pad1.30x1.75mm_HandSolder
R12: 3.3R; R_0805_2012Metric_Pad1.20x1.40mm_HandSolder
RF_OUT1: SMA; SMA_Samtec_SMA-J-P-X-ST-EM1_EdgeMount
RV1: 10k; PinHeader_1x03_P2.54mm_Vertical
RV2: 20k; PinHeader_1x03_P2.54mm_Vertical
RZ1: RP2040-Zero
Rb1: 1k; R_1206_3216Metric_Pad1.30x1.75mm_HandSolder
Rf1: 4.7k; R_1206_3216Metric_Pad1.30x1.75mm_HandSolder
Rin1: 1k; R_1206_3216Metric_Pad1.30x1.75mm_HandSolder
Rl1: 470; R_1206_3216Metric_Pad1.30x1.75mm_HandSolder
SPK1: SPEAKER; PJ-307_Modded
T1: Bifilar XFMR; IND_SRF1260A-4R7Y-Longer-Pads
U1: L7805 (D2PAK); TO-263-2
U2: UCC27517ADBVR; SOT-23-5_HandSoldering
U3: L7812; TO-252-2
U4: AMS1117-3.3; SOT-223-3_TabPin2
U5: SI5351_Module; SI5351 Module
U7: CD2003GB_GP; DIP-16_W7.62mm
U8: MCP6002; DIP-8_W7.62mm

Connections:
12V: C1.1, C2.1, C14.1, C15.1, C18.1, D1.1 (K), D4.1 (K), JP2.1 (A), Q3.3 (S), R8.1, U1.1 (IN)
12V_VIA_LDO: C24.1, C30.1, JP2.3 (B), U3.3 (OUT)
+3.3V: C25.1, C41.1, C42.1, C46.1, R10.1, U4.2 (VO), U5.1 (VIN), U8.8 (V+)
+5V: C8.1, C13.1, C21.1, C28.1, C37.1, C44.1, C45.1, C47.1, D2.2 (A), D3.1 (K), D5.1 (K), D8.1 (K), D9.2 (A), J1.1, J1.7, K1.1, L4.1, L5.2, R6.2, U4.3 (VI), U7.6 (VCC), U7.7 (AM_IF), U7.15 (FM_TUNER)
+VDC: D1.2 (A), Power1.1
/DRAIN: C3.1, Q2.2 (D), T1.1, T1.4
ATU: RZ1.15 (GP14), Rb1.1
CAL: C27.2, RZ1.16 (GP15)
CW_KEY: CW_KEY1.1, RZ1.18 (GP27)
GND: BPF1.3 (GND), BPF1.6 (GND), C1.2, C2.2, C3.2, C4.2, C5.2, C6.2, C8.2, C9.2, C10.2, C11.2, C12.2, C13.2, C14.2, C15.2, C16.2, C17.2, C18.2, C20.2, C21.2, C23.2, C24.2, C25.2, C28.2, C29.1, C30.2, C32.2, C36.2, C37.2, C39.2, C41.2, C42.2, C44.2, C45.2, C46.2, C47.2, CW_KEY1.2, D5.2 (A), EXT_ATU1.S, H1.1, H2.1, H3.1, H4.1, J1.2, J1.5, K1.13, Power1.2, Q1.1 (E), Q2.3 (S), Q4.1 (E), Q5.1 (E), R1.2, R2.2, R7.2, R11.2, RF_OUT1.2 (Ext), RV1.3, RZ1.23 (GND), SPK1.S, U1.2 (GND), U2.2 (GND), U2.4 (IN-), U3.2 (GND), U4.1 (GND), U5.2 (GND), U7.1 (FM_RF_IN), U7.2 (GND_IN), U7.9 (GND_OUT), U8.4 (V-)
LDATA: J1.8, RZ1.4 (GP3)
LPF: C10.1, JP1.1 (A), K1.4, L1.1
unnamed: C7.2, T1.3
unnamed: C11.1, L1.2, L2.1
unnamed: C20.1, EXT_ATU1.R, Rl1.1
unnamed: C31.1, C35.1, R7.1
unnamed: C38.2, RV1.1
unnamed: C43.2, SPK1.R, SPK1.T
unnamed: D2.1 (K), RZ1.22 (5V)
unnamed: D3.2 (A), K1.16, Q1.3 (C)
unnamed: D4.2 (A), Q3.1 (G), Q4.3 (C), R8.2
unnamed: C31.2, D8.2 (A), D9.1 (K), L5.1, U7.16 (AM_RF_IN)
unnamed: F1.1, T1.2
unnamed: C12.1, JP1.2 (B), L2.2, RF_OUT1.1 (In)
unnamed: C16.1, C23.1, JP2.2 (C), U2.1 (VDD)
unnamed: JP4.1 (A), RZ1.17 (GP26)
unnamed: Q1.2 (B), R4.2
unnamed: Q2.1 (G), R1.1, R12.2
unnamed: Q4.2 (B), R9.1
unnamed: Q5.2 (B), Rb1.2
unnamed: Q5.3 (C), Rl1.2
unnamed: RV1.2, Rin1.2
unnamed: C9.1, L4.2, U1.3 (OUT)
unnamed: C19.2, U2.3 (IN+)
unnamed: R12.1, U2.5 (OUT)
unnamed: C27.1, U5.5 (S2)
unnamed: C36.1, U7.5 (AGC)
unnamed: C26.1, R6.1, U7.12 (AM_OSC)
unnamed: C29.2, U7.14 (FM/AM_SW)
unnamed: C39.1, R10.2, R11.1, U8.3 (+), U8.5 (+)
unnamed: C40.2, RV2.1, Rf1.2, Rin1.1, U8.2 (-)
unnamed: U8.6 (-), U8.7
PTT: C4.1, R2.1, R4.1, R9.2, RZ1.9 (GP8)
RF_OUT: C7.1, K1.8
RX: BPF1.1 (ANT), BPF1.2 (ANT), JP3.1 (A), K1.6, K1.9
RX_AFTER_HPF: BPF1.4 (RF), BPF1.5 (RF), C35.2, JP3.2 (B)
RX_AUDIO: C38.1, U7.4 (AM_MIX)
RX_OSC: C26.2, U5.6 (S1)
SCL: RZ1.14 (GP13), U5.4 (SCL)
SCL1: J1.10, RZ1.8 (GP7)
SDA: RZ1.13 (GP12), U5.3 (SDA)
SDA1: J1.9, RZ1.7 (GP6)
TO_ADC: C40.1, C43.1, JP4.2 (B), RV2.2, RV2.3, Rf1.1, U8.1
TUNE: J1.3, RZ1.3 (GP2)
TX_RF: C19.1, U5.7 (SO)
UART_RX: J1.4, RZ1.2 (GP1)
UART_TX: J1.6, RZ1.1 (GP0)
VDC_VIA_PTT: C5.1, C6.1, C17.1, C32.1, F1.2, Q3.2 (D), U3.1 (IN)

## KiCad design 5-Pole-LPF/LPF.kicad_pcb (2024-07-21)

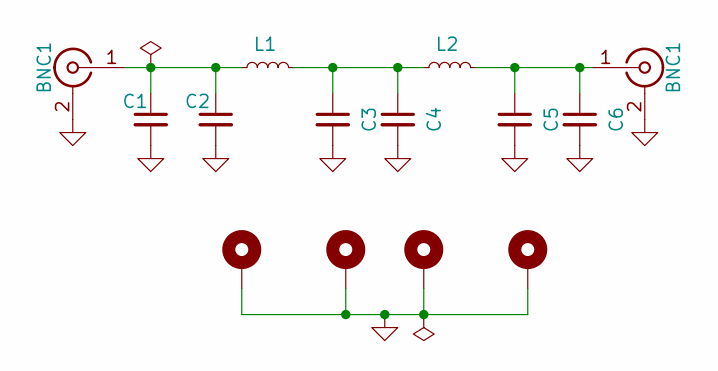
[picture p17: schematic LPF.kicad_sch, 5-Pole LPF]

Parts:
BNC1: SMA; SMA_Samtec_SMA-J-P-H-ST-EM1_EdgeMount
C1, C2, C3, C4, C5, C6: 100n; C_Disc_D5.0mm_W2.5mm_P5.00mm
H1, H2, H3, H4: MountingHole_Pad; MountingHole_2.2mm_M2_Pad_Via
L1, L2: L_Small; L_Toroid_Vertical_L10.0mm_W5.0mm_P5.08mm

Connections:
GND: C1.2, C2.2, C3.2, C4.2, C5.2, C6.2, H1.1, H2.1, H3.1, H4.1; also elsewhere on the board
unnamed: C3.1, C4.1, L1.2, L2.1
unnamed 2: C1.1, C2.1, L1.1; also elsewhere on the board
unnamed 3: C5.1, C6.1, L2.2; also elsewhere on the board

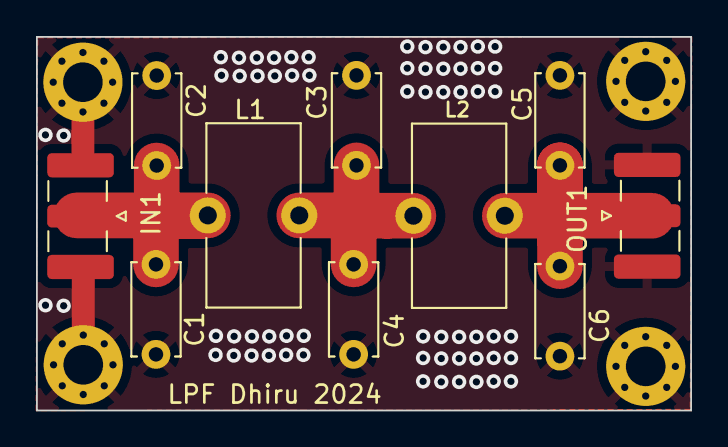
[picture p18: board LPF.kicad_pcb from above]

Board: 2 copper layers, 36.3 x 20.8 mm, 14 parts (0 on the bottom side), 4 nets.

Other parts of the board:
IN1: SMA; SMA_Samtec_SMA-J-P-H-ST-EM1_EdgeMount
OUT1: SMA; SMA_Samtec_SMA-J-P-H-ST-EM1_EdgeMount

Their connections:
GND: IN1.2 (Ext), OUT1.2 (Ext); also elsewhere on the board
unnamed 2: IN1.1 (In); also elsewhere on the board
unnamed 3: OUT1.1 (In); also elsewhere on the board

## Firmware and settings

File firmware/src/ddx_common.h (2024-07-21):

#ifndef DDX_common
#define DDX_common

#define VERSION        "1.0"
#define BUILD          1

#include <stdio.h>
#include <stdint.h>

#include "si5351.h"

#include "hardware/watchdog.h"
// #include <EEPROM.h>
#include "pico/stdlib.h"
#include "pico/binary_info.h"
#include "hardware/gpio.h"
#include "hardware/sync.h"
#include "hardware/structs/ioqspi.h"
#include "hardware/structs/sio.h"
#include "hardware/pwm.h"
#include "pico/multicore.h"
#include "hardware/adc.h"
#include "hardware/uart.h"

// Pinout
#define PTT            8 // PTT pin
#define CAL            15 // Automatic calibration entry
#define TXLED          3
#define GPS            1
#define SDA_PIN        12
#define SCL_PIN        13
#define ATU_PIN        14

// Buttons
#define ABORT_BTN      0 // repurposing the UART_TX pin
#define TUNE_BTN       2

extern uint64_t freq;
extern int32_t cal_factor;

void serialEvent();
void led_flash();

#endif

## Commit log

2024-07-21 The Global Communications Transceiver
    [BOM-HF-PA-v10.csv, CON-SMA-EDGE-S--3DModel-STEP-56544.STEP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]
2025-07-20 Compile FW using latest pico-sdk and tinyusb
